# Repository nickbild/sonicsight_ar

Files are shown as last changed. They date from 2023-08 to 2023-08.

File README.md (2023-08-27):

# SonicSight AR

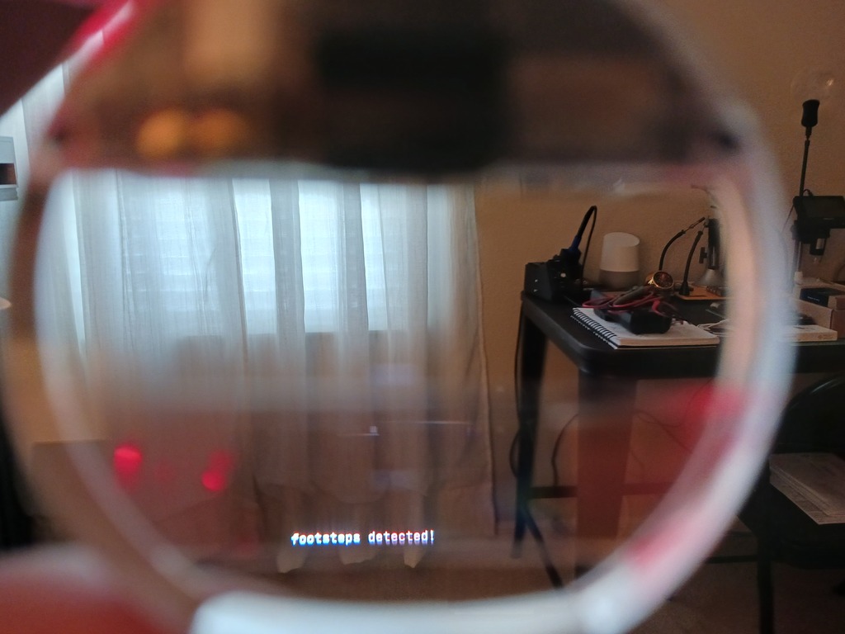
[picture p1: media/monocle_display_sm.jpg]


Hearing-impaired people face significant challenges due to their inability to perceive auditory cues, such as emergency sirens, alarms, and traffic sounds.  These cues are essential for alerting people to potential dangers and ensuring their safety.  Without auditory awareness, hearing-impaired people may not be aware of approaching emergency vehicles, fire alarms, or even oncoming traffic, which can lead to life-threatening situations.

According to the World Health Organization, around 466 million people worldwide have a disabling hearing loss, which accounts for approximately 5% of the global population.  In the United States alone, the Centers for Disease Control and Prevention reported that about 15% of adults aged 18 and over experience some degree of hearing loss.

In an attempt to address this problem, I have created SonicSight AR.  This device uses machine learning to recognize sounds, like emergency vehicles and various types of alarms.  When these sounds are detected, the user of SonicSight AR is alerted to that fact via a message that floats within their field of vision through the use of a low-cost augmented reality display.  SonicSight AR also solves some other unique problems often experienced by the hearing-impaired — it also detects footsteps and talking to prevent the wearer from being startled when someone approaches them unexpectedly.

## How It Works

The Particle Photon 2 development board is wired to a supported PDM MEMS microphone that comes with the Edge ML Kit for Photon 2.  After development is completed, this hardware can be powered by a LiPo battery (a 400 mAh battery was used in this project).

An audio classification neural network was developed with Edge Impulse Studio to distinguish between eight types of sounds (ambulance, danger alarm, fire alarm, firetruck, footsteps, gas alarm, talking, traffic sounds), as well as normal background noises.

When one of the sounds is recognized, the Photon 2 will send a program to a Brilliant Labs Monocle, wirelessly via Bluetooth Low Energy, which is attached to a pair of glasses.  This causes text to be overlaid on the wearer’s peripheral vision.  The text provides a visual alert to warn of a sound that otherwise could not be heard.

The Photon 2, microphone, and battery were placed inside a 3D printed case.  A velcro strap was attached to the case such that it could be attached to a belt.

## Media

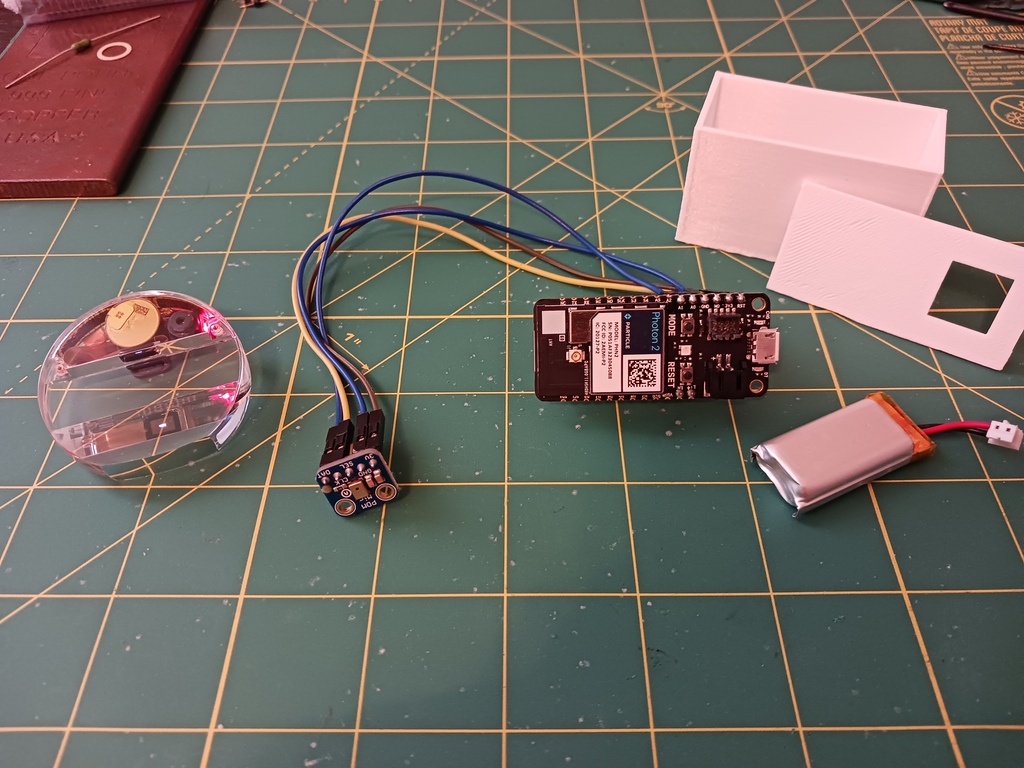
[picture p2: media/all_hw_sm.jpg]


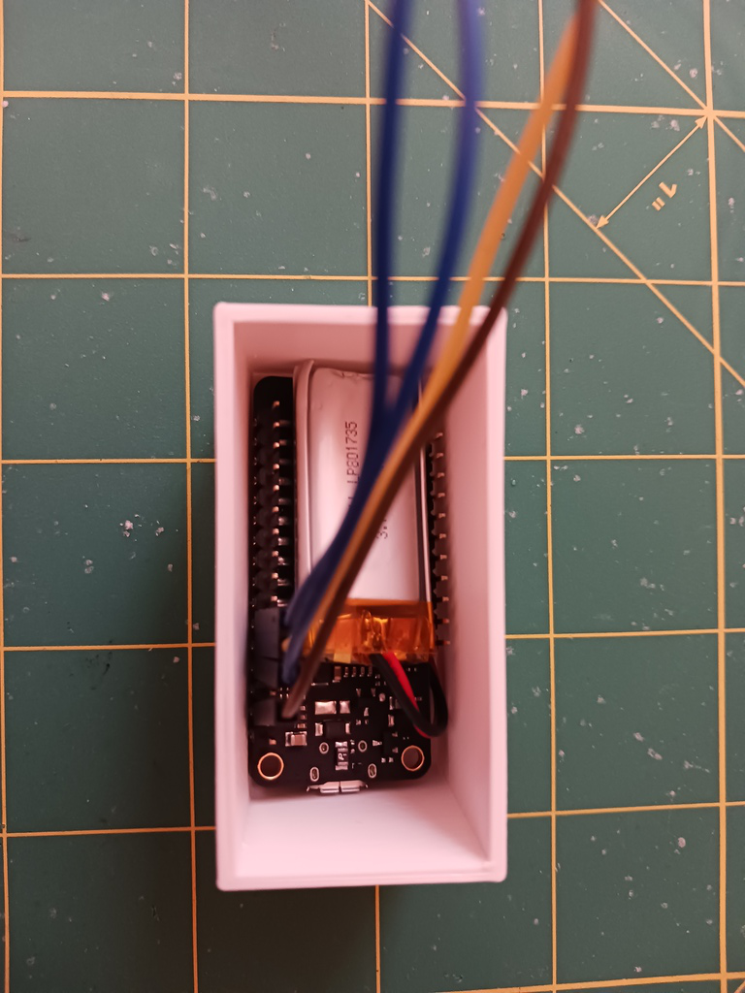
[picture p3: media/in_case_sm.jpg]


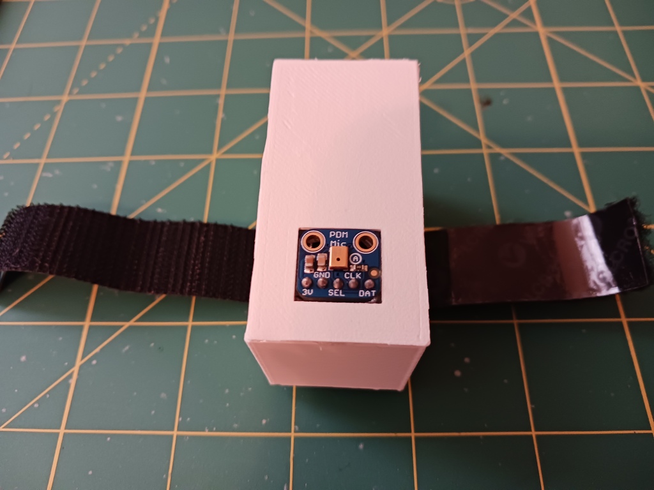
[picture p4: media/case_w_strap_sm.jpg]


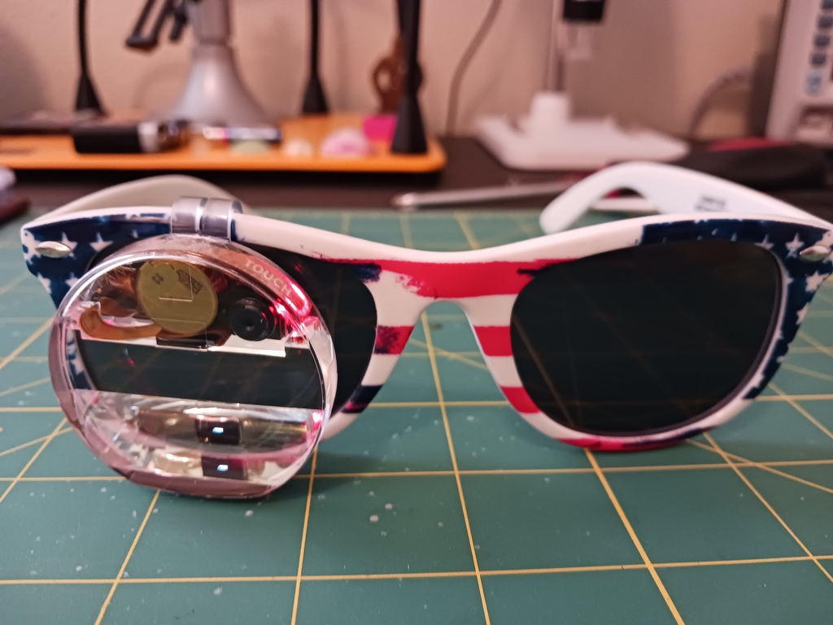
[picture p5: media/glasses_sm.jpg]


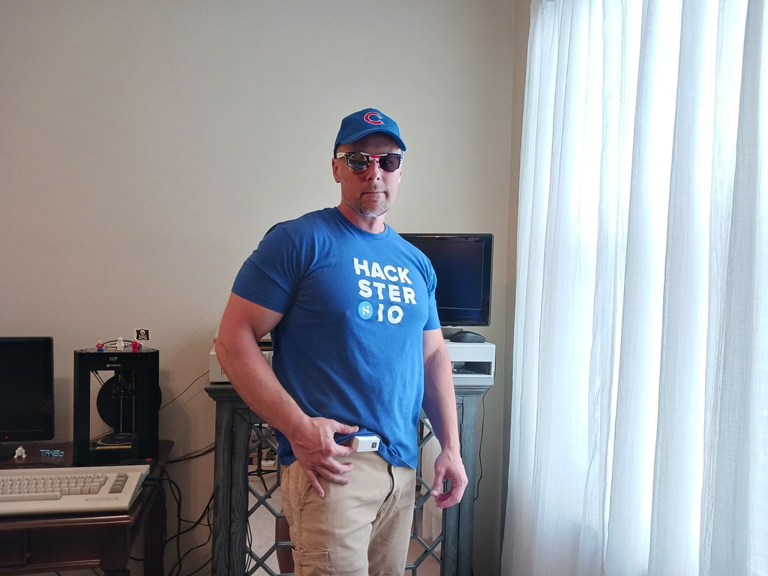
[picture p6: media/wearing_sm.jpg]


## Bill of Materials

- 1 x Particle Photon 2
- 1 x PDM MEMS microphone
- 1 x Brilliant Labs Monocle
- 1 x 400 mAh LiPo battery
- optional 3D printed case and lid
- optional velcro strap

## About the Author
[Nick A. Bild, MS](https://nickbild79.firebaseapp.com/#!/)

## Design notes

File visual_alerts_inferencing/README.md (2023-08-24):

# Exported Edge Impulse's Particle Library for visual_alerts_inferencing

## To use in Particle Workbench

1. In Workbench, select **Particle: Import Project** and select the `project.properties` file in the directory that you just downloaded and extracted.

1. Use **Particle: Configure Project for Device** and select **deviceOS@5.3.2** and choose a target. (e.g. **P2** , this option is also used for the Photon 2).

1. Compile with  **Particle: Compile application (local)**

1. Flash with **Particle: Flash application (local)**

> At this time you cannot use the **Particle: Cloud Compile** or **Particle: Cloud Flash** options; local compilation is required.

## Examples

`src/main.cpp` already contains one of the examples found in `examples/` directory.  If
you wish to use a different example, copy the `main.cpp` file from the example
in the `examples/` directory and replace `src/main.cpp`.

You may need to install additional libraries using **Particle: Install Library**
for some examples. See the example source for details.

### static_buffer

The `static_buffer` example can be used to feed raw features directly for
inference on target.  Copy raw features from the **Live classifiaction** page of
your project into the `features` array. For more information see
https://docs.edgeimpulse.com/docs/deployment/running-your-impulse-particle.

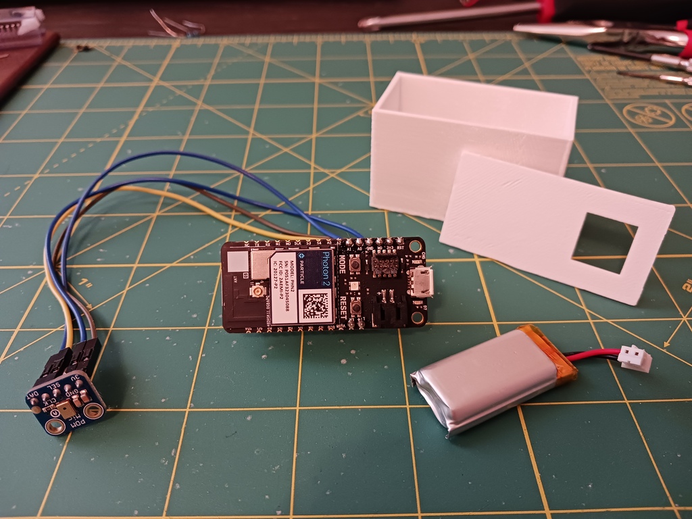
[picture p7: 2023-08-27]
media/photon_sm.jpg

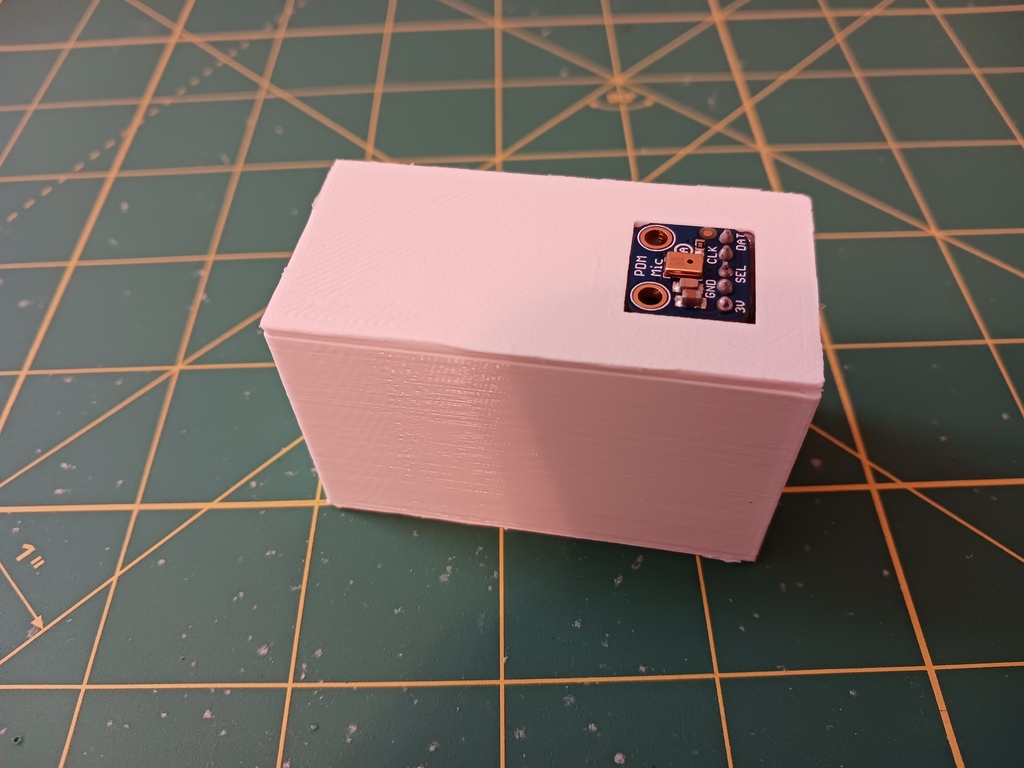
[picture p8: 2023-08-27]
media/case_sm.jpg

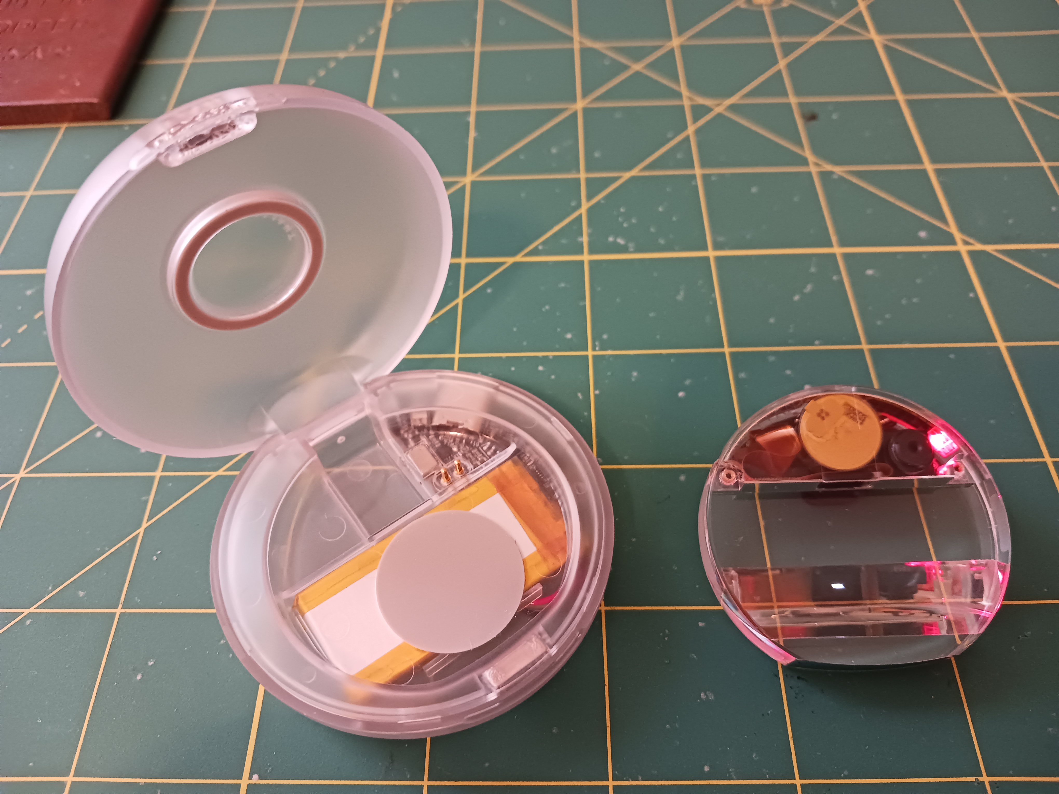
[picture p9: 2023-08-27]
media/monocle.jpg

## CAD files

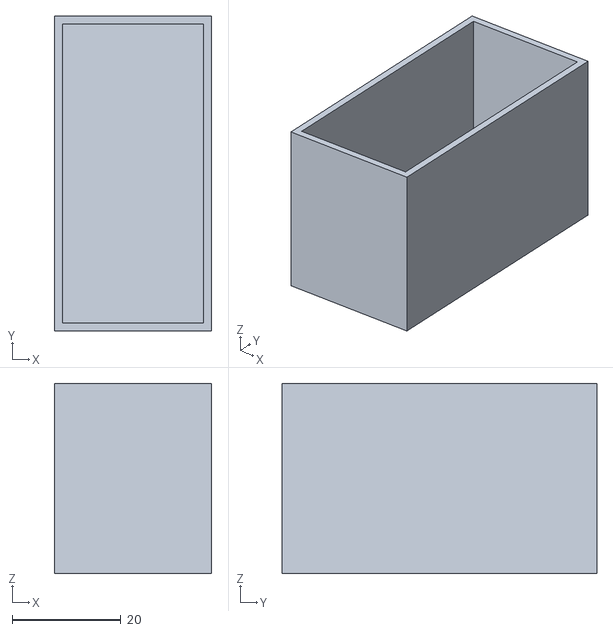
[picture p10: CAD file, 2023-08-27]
case.stl
29.0 x 58.0 x 35.0

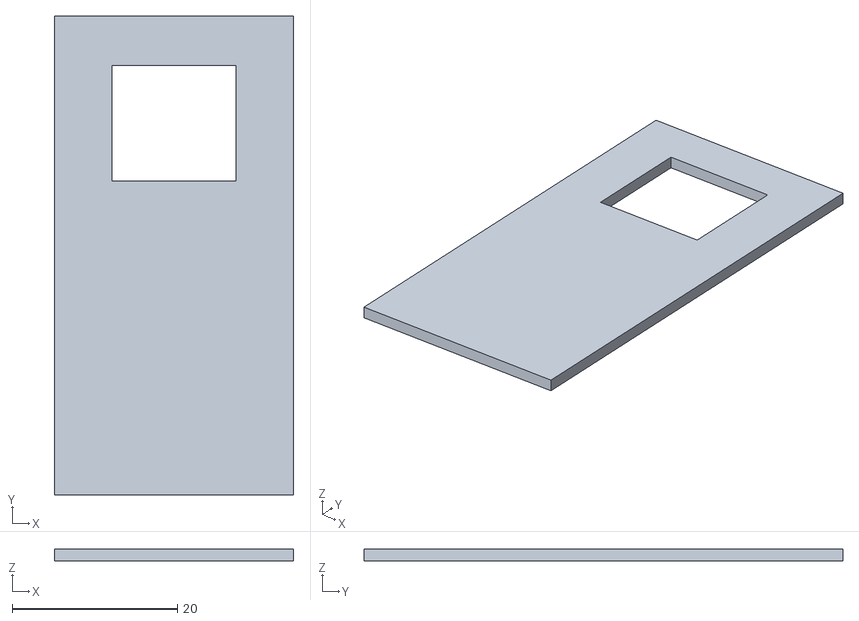
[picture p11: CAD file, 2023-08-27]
lid.stl
29.0 x 58.0 x 1.50

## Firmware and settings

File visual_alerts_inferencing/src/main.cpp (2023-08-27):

/*
 * Copyright (c) 2023 EdgeImpulse Inc.
 *
 * Licensed under the Apache License, Version 2.0 (the "License");
 * you may not use this file except in compliance with the License.
 * You may obtain a copy of the License at
 * http://www.apache.org/licenses/LICENSE-2.0
 *
 * Unless required by applicable law or agreed to in writing,
 * software distributed under the License is distributed on an "AS
 * IS" BASIS, WITHOUT WARRANTIES OR CONDITIONS OF ANY KIND, either
 * express or implied. See the License for the specific language
 * governing permissions and limitations under the License.
 *
 * SPDX-License-Identifier: Apache-2.0
 */

/* Include ----------------------------------------------------------------- */
#include "Particle.h"
#include "Microphone_PDM.h"
#include <visual_alerts_inferencing.h>
#include <cstdint>

SYSTEM_THREAD(ENABLED);

SerialLogHandler logHandler(LOG_LEVEL_ERROR);

/* Forward declerations ---------------------------------------------------- */
int raw_feature_get_data(size_t offset, size_t length, float *out_ptr);
void setup();
void loop();

/** Audio buffers, pointers and selectors */
typedef struct {
    int16_t *buffer;
    uint8_t buf_ready;
    uint32_t buf_count;
    uint32_t n_samples;
} inference_t;

BlePeerDevice peer;
BleCharacteristic rx_characteristic;

static inference_t inference;

static bool microphone_inference_start(uint32_t n_samples);
static bool microphone_inference_record(void);
static int microphone_audio_signal_get_data(size_t offset, size_t length, float *out_ptr);
static void microphone_inference_end(void);


void print_inference_result(ei_impulse_result_t result);

/**
 * @brief      Particle setup function
 */
void setup()
{
    // put your setup code here, to run once:

    // Wait for serial to make it easier to see the serial logs at startup.
    waitFor(Serial.isConnected, 4000);
    delay(2000);

    ei_printf("Edge Impulse inference runner for Particle devices\r\n");

    int err = Microphone_PDM::instance()
        .withOutputSize(Microphone_PDM::OutputSize::SIGNED_16)
        .withRange(Microphone_PDM::Range::RANGE_32768)
        .withSampleRate(EI_CLASSIFIER_FREQUENCY)
        .init();

    if (err) {
        ei_printf("PDM decoder init err=%d", err);
    }

    // summary of inferencing settings (from model_metadata.h)
    ei_printf("Inferencing settings:\n");
    ei_printf("\tInterval: %.2f ms.\n", (float)EI_CLASSIFIER_INTERVAL_MS);
    ei_printf("\tFrame size: %d\n", EI_CLASSIFIER_DSP_INPUT_FRAME_SIZE);
    ei_printf("\tSample length: %d ms.\n", EI_CLASSIFIER_RAW_SAMPLE_COUNT / 16);
    ei_printf("\tNo. of classes: %d\n", sizeof(ei_classifier_inferencing_categories) / sizeof(ei_classifier_inferencing_categories[0]));

    if (microphone_inference_start(EI_CLASSIFIER_RAW_SAMPLE_COUNT) == false) {
        ei_printf("ERR: Could not allocate audio buffer (size %d), this could be due to the window length of your model\r\n", EI_CLASSIFIER_RAW_SAMPLE_COUNT);
        return;
    }
}

/**
 * @brief      Particle main function
 */
void loop()
{
    // If not connected to the Monocle yet, do so now.
    if (!peer.connected()) {
        Vector<BleScanResult> scanResults = BLE.scan();

        if (scanResults.size()) {
            ei_printf("%d BLE devices found", scanResults.size());

            for (int ii = 0; ii < scanResults.size(); ii++) {
                ei_printf("MAC: %02X:%02X:%02X:%02X:%02X:%02X | RSSI: %dBm",
                        scanResults[ii].address()[0], scanResults[ii].address()[1], scanResults[ii].address()[2],
                        scanResults[ii].address()[3], scanResults[ii].address()[4], scanResults[ii].address()[5], scanResults[ii].rssi());

                String name = scanResults[ii].advertisingData().deviceName();
                if (name.length() > 0) {
                    ei_printf("Advertising name: %s", name.c_str());
                
                    if (strcmp(name, "monocle") == 0) {
                        ei_printf("Trying connection...%s\n", name);
                        peer = BLE.connect(scanResults[ii].address());
                        if (peer.connected()) {
                            ei_printf("Successfully connected!\n");
                            bool bResult = peer.getCharacteristicByUUID(rx_characteristic, BleUuid("6e400002-b5a3-f393-e0a9-e50e24dcca9e"));
                            if (bResult) {
                                ei_printf("Characteristic found.\n");
                            } else {
                                ei_printf("ERROR: characteristic NOT found\n");
                            }
                        }
                        else {
                            ei_printf("Monocle connection failed.\n");
                        }
                    }
                }
            }
        }
    }

    ei_printf("Starting inferencing soon...\n");

    delay(500);

    ei_printf("Recording...\n");

    bool m = microphone_inference_record();
    if (!m) {
        ei_printf("ERR: Failed to record audio...\n");
        return;
    }

    ei_printf("Recording done\n");

    signal_t signal;
    signal.total_length = EI_CLASSIFIER_RAW_SAMPLE_COUNT;
    signal.get_data = &microphone_audio_signal_get_data;

    ei_impulse_result_t result = { 0 };

    // invoke the impulse
    EI_IMPULSE_ERROR res = run_classifier(&signal, &result, false /* debug */);
    if (res != EI_IMPULSE_OK) {
        ei_printf("ERR: Failed to run classifier (%d)\n", res);
        return;
    }

    // print inference return code
    ei_printf("run_classifier returned: %d\r\n", res);
    print_inference_result(result);

    delay(1000);
}

void print_inference_result(ei_impulse_result_t result) {

    // Print how long it took to perform inference
    ei_printf("Timing: DSP %d ms, inference %d ms, anomaly %d ms\r\n",
            result.timing.dsp,
            result.timing.classification,
            result.timing.anomaly);

    // Print the prediction results (object detection)
#if EI_CLASSIFIER_OBJECT_DETECTION == 1
    ei_printf("Object detection bounding boxes:\r\n");
    for (uint32_t i = 0; i < result.bounding_boxes_count; i++) {
        ei_impulse_result_bounding_box_t bb = result.bounding_boxes[i];
        if (bb.value == 0) {
            continue;
        }
        ei_printf("  %s (%f) [ x: %u, y: %u, width: %u, height: %u ]\r\n",
                bb.label,
                bb.value,
                bb.x,
                bb.y,
                bb.width,
                bb.height);
    }

    // Print the prediction results (classification)
#else
    ei_printf("Predictions:\r\n");
    for (uint16_t i = 0; i < EI_CLASSIFIER_LABEL_COUNT; i++) {
        ei_printf("  %s: ", ei_classifier_inferencing_categories[i]);
        ei_printf("%.5f\r\n", result.classification[i].value);

        // If there is a high-confidence prediction, write it to the Monocle.
        if (result.classification[i].value > 0.7 && ei_classifier_inferencing_categories[i] != "background") {
            if (peer.connected()) {
                rx_characteristic.setValue("\x01");
                rx_characteristic.setValue("import display\n");
                rx_characteristic.setValue("display.clear()\n");
                rx_characteristic.setValue("tt = display.Text(\"");
                rx_characteristic.setValue(ei_classifier_inferencing_categories[i]);
                rx_characteristic.setValue(" detected!\", 150, 150, 0xffffff)\n");
                rx_characteristic.setValue("display.show(tt)\n");
                rx_characteristic.setValue("\x04");
            }
        }
    }
#endif

    // Print anomaly result (if it exists)
#if EI_CLASSIFIER_HAS_ANOMALY == 1
    ei_printf("Anomaly prediction: %.3f\r\n", result.anomaly);
#endif

}

static int16_t *sptr;
static uint32_t sample_length = 0;

/**
 * @brief      PDM buffer full callback
 *             Get data and call audio thread callback
 */
static void pdm_data_ready_inference_callback(void)
{
    bool dma_ready = Microphone_PDM::instance().noCopySamples([](void *pSamples, size_t numSamples) {

        sample_length = Microphone_PDM::instance().getBufferSizeInBytes() / 2;
        sptr = (int16_t *)pSamples;
    });

    if(sample_length && dma_ready) {

        if (inference.buf_ready == 0) {
            for(int i = 0; i < sample_length; i++) {
                inference.buffer[inference.buf_count++] = sptr[i];

                if(inference.buf_count >= inference.n_samples) {
                    inference.buf_count = 0;
                    inference.buf_ready = 1;
                    break;
                }
            }
        }
    }
}

/**
 * @brief      Init inferencing struct and setup/start PDM
 *
 * @param[in]  n_samples  The n samples
 *
 * @return     { description_of_the_return_value }
 */
static bool microphone_inference_start(uint32_t n_samples)
{
    inference.buffer = (int16_t *)malloc(n_samples * sizeof(int16_t));

    if(inference.buffer == NULL) {
        return false;
    }

    inference.buf_count  = 0;
    inference.n_samples  = n_samples;
    inference.buf_ready  = 0;

    if (Microphone_PDM::instance().start()) {
        ei_printf("Failed to start PDM!");
        microphone_inference_end();

        return false;
    }

    return true;
}

/**
 * @brief      Wait on new data
 *
 * @return     True when finished
 */
static bool microphone_inference_record(void)
{
    inference.buf_ready = 0;
    inference.buf_count = 0;

    uint64_t sample_start_us = ei_read_timer_us();

    /* Empty DMA buffers */
    while(Microphone_PDM::instance().noCopySamples([](void *pSamples, size_t numSamples){})){};

    while(inference.buf_ready == 0) {

        pdm_data_ready_inference_callback();
    }

    ei_printf("Sample time: %d\r\n", (int) (ei_read_timer_us() - sample_start_us) / 1000);

    return true;
}

/**
 * Get raw audio signal data
 */
static int microphone_audio_signal_get_data(size_t offset, size_t length, float *out_ptr)
{
    numpy::int16_to_float(&inference.buffer[offset], out_ptr, length);

    return 0;
}

/**
 * @brief      Stop PDM and release buffers
 */
static void microphone_inference_end(void)
{
    Microphone_PDM::instance().stop();
    free(inference.buffer);
}

#if !defined(EI_CLASSIFIER_SENSOR) || EI_CLASSIFIER_SENSOR != EI_CLASSIFIER_SENSOR_MICROPHONE
#error "Invalid model for current sensor."
#endif

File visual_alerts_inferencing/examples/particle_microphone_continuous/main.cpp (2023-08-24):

/* Edge Impulse ingestion SDK
 * Copyright (c) 2022 EdgeImpulse Inc.
 *
 * Licensed under the Apache License, Version 2.0 (the "License");
 * you may not use this file except in compliance with the License.
 * You may obtain a copy of the License at
 * http://www.apache.org/licenses/LICENSE-2.0
 *
 * Unless required by applicable law or agreed to in writing, software
 * distributed under the License is distributed on an "AS IS" BASIS,
 * WITHOUT WARRANTIES OR CONDITIONS OF ANY KIND, either express or implied.
 * See the License for the specific language governing permissions and
 * limitations under the License.
 *
 */

// If your target is limited in memory remove this macro to save 10K RAM
#define EIDSP_QUANTIZE_FILTERBANK   0

/**
 * Define the number of slices per model window. E.g. a model window of 1000 ms
 * with slices per model window set to 4. Results in a slice size of 250 ms.
 * For more info: https://docs.edgeimpulse.com/docs/continuous-audio-sampling
 */
#define EI_CLASSIFIER_SLICES_PER_MODEL_WINDOW 4

/* Includes ---------------------------------------------------------------- */
#include "Microphone_PDM.h"
#include "Particle.h"
#include <visual_alerts_inferencing.h>

SYSTEM_THREAD(ENABLED);
SerialLogHandler logHandler(LOG_LEVEL_ERROR);

/* Forward declerations ---------------------------------------------------- */
static bool microphone_inference_start(uint32_t n_samples);
static bool microphone_inference_record(void);
static void microphone_inference_end(void);
static int microphone_audio_signal_get_data(size_t offset, size_t length, float *out_ptr);

/** Audio buffers, pointers and selectors */
typedef struct {
    signed short *buffers[2];
    unsigned char buf_select;
    unsigned char buf_ready;
    unsigned int buf_count;
    unsigned int n_samples;
} inference_t;

static inference_t inference;
static bool record_ready = false;
static signed short *sampleBuffer;
static bool debug_nn = false; // Set this to true to see e.g. features generated from the raw signal
static int print_results = -(EI_CLASSIFIER_SLICES_PER_MODEL_WINDOW);

/**
 * @brief      Particle setup function
 */
void setup()
{
    // put your setup code here, to run once:

    // Wait for serial to make it easier to see the serial logs at startup.
    waitFor(Serial.isConnected, 15000);
    delay(2000);

    ei_printf("Edge Impulse inference runner for Particle devices\r\n");

    // summary of inferencing settings (from model_metadata.h)
    ei_printf("Inferencing settings:\n");
    ei_printf("\tInterval: %.2f ms.\n", (float)EI_CLASSIFIER_INTERVAL_MS);
    ei_printf("\tFrame size: %d\n", EI_CLASSIFIER_DSP_INPUT_FRAME_SIZE);
    ei_printf("\tSample length: %d ms.\n", EI_CLASSIFIER_RAW_SAMPLE_COUNT / 16);
    ei_printf("\tNo. of classes: %d\n", sizeof(ei_classifier_inferencing_categories) /
                                            sizeof(ei_classifier_inferencing_categories[0]));

    run_classifier_init();
    if (microphone_inference_start(EI_CLASSIFIER_SLICE_SIZE) == false) {
        ei_printf("ERR: Could not allocate audio buffer (size %d), this could be due to the window length of your model\r\n", EI_CLASSIFIER_RAW_SAMPLE_COUNT);
        return;
    }
}

/**
 * @brief      Particle main function. Runs the inferencing loop.
 */
void loop()
{
    bool m = microphone_inference_record();
    if (!m) {
        ei_printf("ERR: Failed to record audio...\n");
        return;
    }

    signal_t signal;
    signal.total_length = EI_CLASSIFIER_SLICE_SIZE;
    signal.get_data = &microphone_audio_signal_get_data;
    ei_impulse_result_t result = {0};

    EI_IMPULSE_ERROR r = run_classifier_continuous(&signal, &result, debug_nn);
    if (r != EI_IMPULSE_OK) {
        ei_printf("ERR: Failed to run classifier (%d)\n", r);
        return;
    }

    if (++print_results >= (EI_CLASSIFIER_SLICES_PER_MODEL_WINDOW)) {
        // print the predictions
        ei_printf("Predictions ");
        ei_printf("(DSP: %d ms., Classification: %d ms., Anomaly: %d ms.)",
            result.timing.dsp, result.timing.classification, result.timing.anomaly);
        ei_printf(": \n");
        for (size_t ix = 0; ix < EI_CLASSIFIER_LABEL_COUNT; ix++) {
            ei_printf("    %s: %.5f\n", result.classification[ix].label,
                      result.classification[ix].value);
        }
#if EI_CLASSIFIER_HAS_ANOMALY == 1
        ei_printf("    anomaly score: %.3f\n", result.anomaly);
#endif

        print_results = 0;
    }
}

static int16_t *sptr;
static uint32_t sample_length = 0;

/**
 * @brief      PDM buffer full callback
 *             Get data and call audio thread callback
 */
static void pdm_data_ready_inference_callback(void)
{
    bool dma_ready = Microphone_PDM::instance().noCopySamples([](void *pSamples, size_t numSamples) {

        sample_length = Microphone_PDM::instance().getBufferSizeInBytes() / 2;
        sptr = (int16_t *)pSamples;
    });

    if (record_ready == true && dma_ready) {

        for (int i = 0; i < sample_length; i++) {
            inference.buffers[inference.buf_select][inference.buf_count++] = sptr[i];

            if (inference.buf_count >= inference.n_samples) {
                inference.buf_select ^= 1;
                inference.buf_count = 0;
                inference.buf_ready = 1;
            }
        }
    }
}

/**
 * @brief      Init inferencing struct and setup/start PDM
 *
 * @param[in]  n_samples  The n samples
 *
 * @return     { description_of_the_return_value }
 */
static bool microphone_inference_start(uint32_t n_samples)
{
    inference.buffers[0] = (signed short *)malloc(n_samples * sizeof(signed short));

    if (inference.buffers[0] == NULL) {
        return false;
    }

    inference.buffers[1] = (signed short *)malloc(n_samples * sizeof(signed short));

    if (inference.buffers[1] == NULL) {
        free(inference.buffers[0]);
        return false;
    }

    sampleBuffer = (signed short *)malloc((n_samples >> 1) * sizeof(signed short));

    if (sampleBuffer == NULL) {
        free(inference.buffers[0]);
        free(inference.buffers[1]);
        return false;
    }

    inference.buf_select = 0;
    inference.buf_count = 0;
    inference.n_samples = n_samples;
    inference.buf_ready = 0;

	int err = Microphone_PDM::instance()
		.withOutputSize(Microphone_PDM::OutputSize::SIGNED_16)
		.withRange(Microphone_PDM::Range::RANGE_32768)
		.withSampleRate(16000)
		.init();

	if (err) {
		ei_printf("PDM decoder init err=%d\r\n", err);
	}

    if (Microphone_PDM::instance().start()) {
        ei_printf("Failed to start PDM!");
        microphone_inference_end();

        return false;
    }

    record_ready = true;

    return true;
}
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
